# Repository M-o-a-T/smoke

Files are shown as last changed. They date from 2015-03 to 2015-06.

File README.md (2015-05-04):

# Fire Detector

## Gira

The "Gira" board is intended to plug into a "Gira Dual" smoke detector.
This device (30€) has a thermometer as well as a smoke chamber, a
serial interface that's actually useful, and the ability to run on 12V
external as well as 9V battery power.

It runs on 3.3V; the 1wire bus (5V) is connected via a level shifter.

Code will be in https://github.com/M-o-a-T/owslave

## Funk

The "Funk" board is a small (and currently untested) board that connects
a cheap smoke detector to RF. There's no code for it.

## Programming

The programming interface is a standard 6-pin plug, except that it's
used via a 3x2 pogo plug. If you need to attach a 6-pin header, soldering
that to the top of the pads is fairly easy. You should add some
two-component glue after soldering so that you won't pull the pads off when
you unplug.

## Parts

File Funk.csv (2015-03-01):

Bill of Material from rauchmelder.sch, 25 parts, grouped by values, as of 1/30/13 1:05 PM
Part | Value | Device | Package | Description | Description2 | Qty | Place_YES/NO | Povided_by_customer_YES/NO | Distributor | Ordernumber | Weblink | Remarks_customer | Unit_price | Total_price | REMARKS_BETA | OPTION1 | OPTION2 | OPTION3
C1, C2 | 1u | C-EUC0603 | C0603 | CAPACITOR, European symbol |  | 2 | YES | NO | RS | 749-2033
C3, C4 | 100n | C-EUC0603 | C0603 | CAPACITOR, European symbol |  | 2 | YES | NO | RS | 698-3232
D1 | 3V | ZENER-DIODESOD80C | SOD80C | Z-Diode |  | 1 | YES | NO | RS | 710-4339
IC1 | MCP1703CB | MCP1703CB | SOT23 | 250 mA, 16V, Low Quiescent Current LDO Regulator |  | 1 | YES | NO | RS | 669-4907
IC2 | MEGA8-MITQFP | MEGA8-MITQFP | TQFP32-08 | MICROCONTROLLER |  | 1 | YES | NO | RS | 719-4039
IC3 | RFM12B | RFM12B | RFM12B | Radio |  | 1 | YES | NO | RS | 731-2785
Q1, Q4, Q5 | 2N7002_SMD | 2N7002_SMD | SOT23 | N-Channel MOSFET |  | 3 | YES | NO | RS | 708-2396
Q2, Q3 | NX3008 | NX3008 | SOT23 | P-channel MOSFET |  | 2 | YES | NO | RS | 669-7376
R2, R3, R4, R6, R7, R8 | 100k | R-EU_R0603 | R0603 | RESISTOR, European symbol | RESISTOR, 0.1W, 1% | 6 | YES | NO | RS | 697-9438 | http://de.rs-online.com/web/p/products/6979438/?searchTerm=697-9438
R5 | 10k | R-EU_R0603 | R0603 | RESISTOR, European symbol | RESISTOR, 0.1W, 1% | 1 | YES | NO | RS | 697-9325 | http://uk.rs-online.com/web/search/searchBrowseAction.html?method=getProduct&R=6979325

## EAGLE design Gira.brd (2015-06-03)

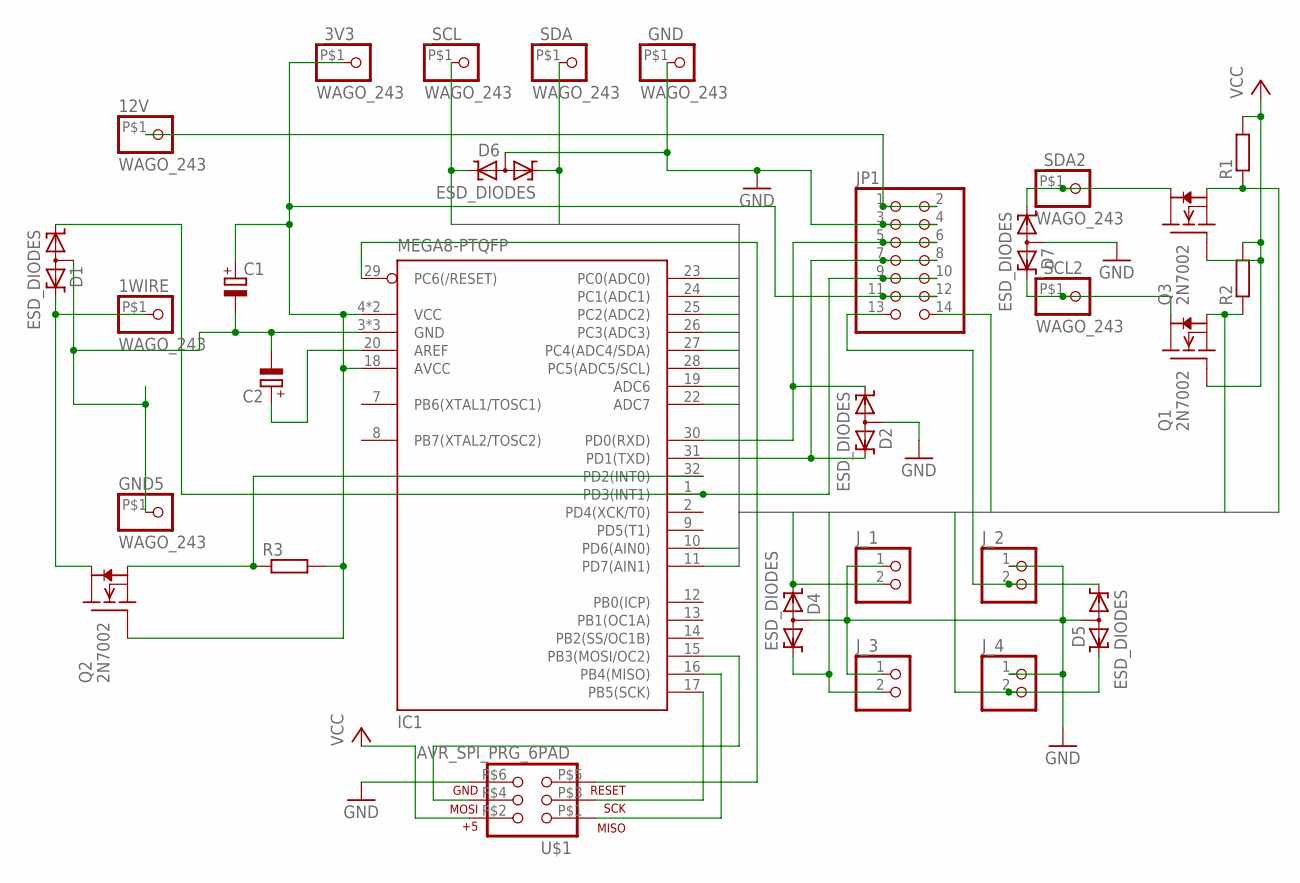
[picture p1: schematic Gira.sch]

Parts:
1WIRE, 12V: WAGO_243
C1, C2: CP1206
D1, D2, D4, D5, D6, D7: ESD_DIODES; SOT23
GND5: WAGO_243
IC1: MEGA8-PTQFP; TQFP32-08
JP1: PINHD-2X7; 2X07
J_1, J_2, J_3, J_4: PINHD-1X2LEVER; 1X02_GN
Q1, Q2, Q3: 2N7002; SOT23
R1, R2, R3: R-EU_R0603; R0603
U$1: AVR_SPI_PRG_6PAD; 2X3_PAD
_3V3: WAGO_243
_GND: WAGO_243
_SCL, _SCL2: WAGO_243
_SDA, _SDA2: WAGO_243

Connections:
3V3: C1.+, IC1.4 (VCC), IC1.6 (VCC), IC1.18 (AVCC), JP1.11, JP1.12, Q2.1 (G), R3.2, U$1.P$2 (2), _3V3.P$1
B1: D4.2 (K2), IC1.23 (PC0(ADC0)), J_1.2
B2: D5.1 (K1), IC1.24 (PC1(ADC1)), J_2.2
B3: D4.1 (K1), IC1.25 (PC2(ADC2)), J_3.2
B4: D5.2 (K2), IC1.26 (PC3(ADC3)), J_4.2
GND: C1.-, C2.-, D1.3 (AA), D2.3 (AA), D4.3 (AA), D5.3 (AA), D6.3 (AA), D7.3 (AA), GND5.P$1, IC1.3 (GND), IC1.5 (GND), IC1.21 (GND), JP1.3, JP1.4, J_1.1, J_2.1, J_3.1, J_4.1, U$1.P$6 (6), _GND.P$1
unnamed: C2.+, IC1.20 (AREF)
unnamed: IC1.32 (PD2(INT0)), Q2.2 (S), R3.1
unnamed: 1WIRE.P$1, D1.2 (K2), Q2.3 (D)
unnamed: D7.1 (K1), Q3.3 (D), _SDA2.P$1
unnamed: D7.2 (K2), Q1.3 (D), _SCL2.P$1
unnamed: IC1.15 (PB3(MOSI/OC2)), U$1.P$4 (4)
unnamed: IC1.16 (PB4(MISO)), U$1.P$1 (1)
unnamed: IC1.17 (PB5(SCK)), U$1.P$3 (3)
unnamed: IC1.29 (PC6(/RESET)), U$1.P$5 (5)
unnamed: 12V.P$1, JP1.1, JP1.2
unnamed: D2.2 (K2), IC1.31 (PD1(TXD)), JP1.7, JP1.8
unnamed: D2.1 (K1), IC1.30 (PD0(RXD)), JP1.5, JP1.6
unnamed: D1.1 (K1), IC1.1 (PD3(INT1)), JP1.9, JP1.10
RESET: IC1.10 (PD6(AIN0)), JP1.13
SCL: D6.2 (K2), IC1.22 (ADC7), _SCL.P$1
SCL2: IC1.28 (PC5(ADC5/SCL)), Q1.2 (S), R2.1
SDA: D6.1 (K1), IC1.19 (ADC6), _SDA.P$1
SDA2: IC1.27 (PC4(ADC4/SDA)), Q3.2 (S), R1.1
TEST: IC1.11 (PD7(AIN1)), JP1.14
VCC: Q1.1 (G), Q3.1 (G), R1.2, R2.2

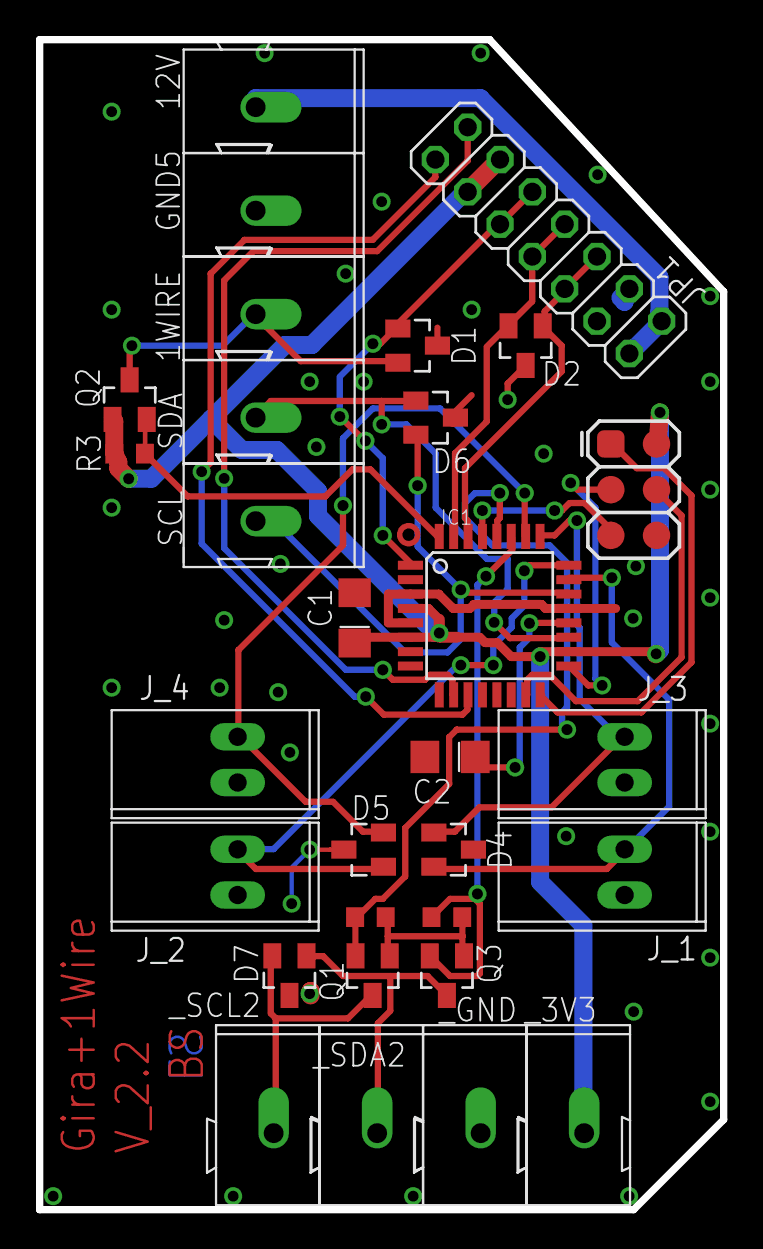
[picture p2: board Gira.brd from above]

Board: 2 copper layers, 38.0 x 65.0 mm, 30 parts (0 on the bottom side), 26 nets.

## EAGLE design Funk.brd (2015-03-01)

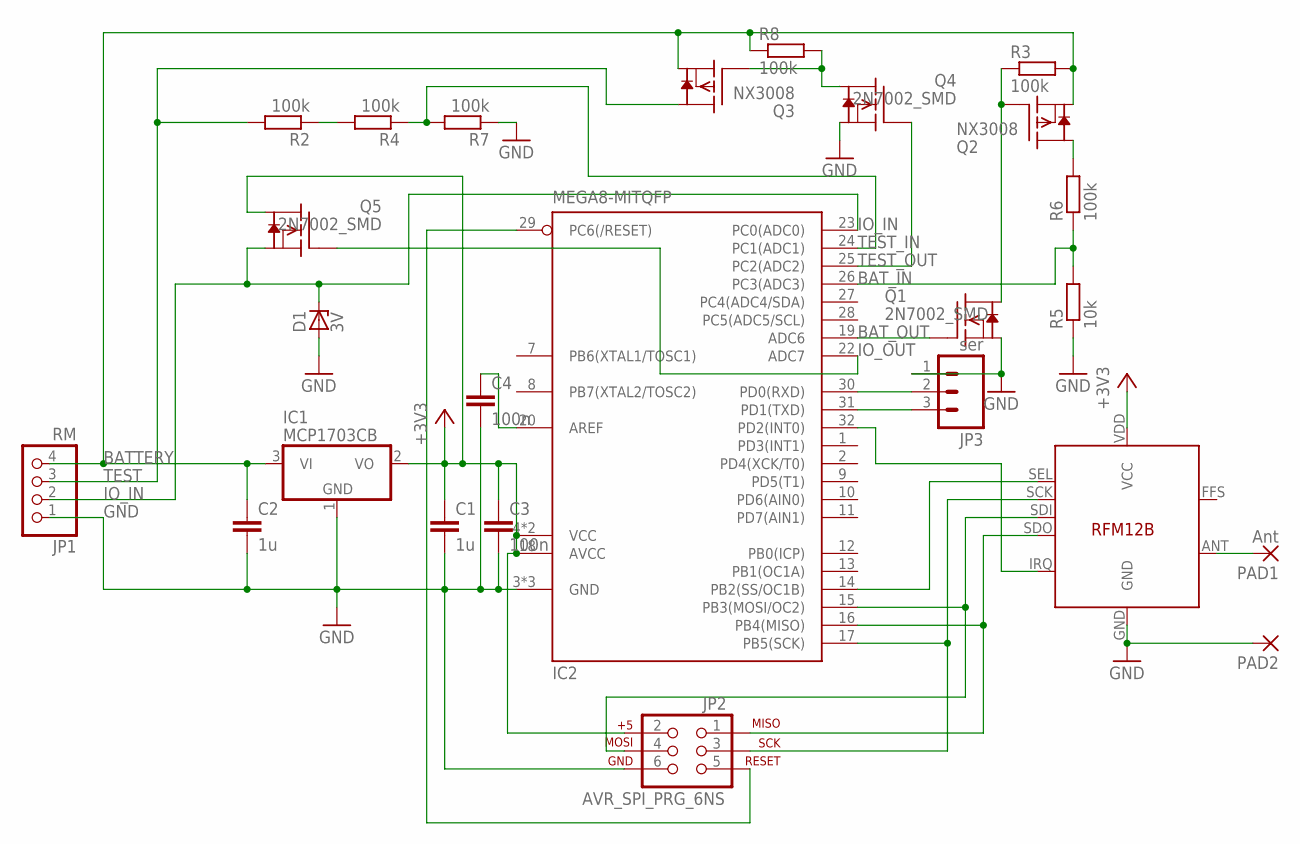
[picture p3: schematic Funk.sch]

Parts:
C1, C2: 1u; C0603
C3, C4: 100n; C0603
D1: 3V; SOD80C
IC1: MCP1703CB; SOT23
IC2: MEGA8-MITQFP; TQFP32-08
IC3: RFM12B; MPN RFM12B-868-S1
JP1: RM; 1X04
JP2: AVR_SPI_PRG_6NS; 2X3-NS
JP3: ser; 1X03
PAD1: Ant; 1,6/0,8
PAD2: 1,6/0,8
Q1, Q4, Q5: 2N7002_SMD; SOT23
Q2, Q3: NX3008; SOT23; MPN NX3008NBK
R2, R3, R4, R6, R7, R8: 100k; R0603
R5: 10k; R0603

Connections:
+3V3: C1.1, C3.1, IC1.2 (VO), IC2.4 (VCC), IC2.6 (VCC), IC2.18 (AVCC), IC3.VDD (VCC), JP2.2, Q5.3 (D)
BATTERY: C2.1, IC1.3 (VI), JP1.4, Q2.2 (S), Q3.2 (S), R3.2, R8.1
BAT_IN: IC2.26 (PC3(ADC3)), R5.2, R6.1
BAT_OUT: IC2.19 (ADC6), Q1.1 (G)
GND: C1.2, C2.2, C3.2, C4.2, D1.A, IC1.1 (GND), IC2.3 (GND), IC2.5 (GND), IC2.21 (GND), IC3.GND, JP1.1, JP2.6, JP3.1, PAD2.1, Q1.2 (S), Q4.2 (S), R5.1, R7.1
IO_IN: D1.C, IC2.23 (PC0(ADC0)), JP1.2, Q5.2 (S)
IO_OUT: IC2.22 (ADC7), Q5.1 (G)
unnamed: R2.1, R4.2
unnamed: IC2.29 (PC6(/RESET)), JP2.5
unnamed: Q2.3 (D), R6.2
unnamed: IC2.16 (PB4(MISO)), IC3.SDO, JP2.1
unnamed: IC2.15 (PB3(MOSI/OC2)), IC3.SDI, JP2.4
unnamed: IC2.17 (PB5(SCK)), IC3.SCK, JP2.3
unnamed: IC2.14 (PB2(SS/OC1B)), IC3.SEL
unnamed: IC2.32 (PD2(INT0)), IC3.IRQ
unnamed: Q1.3 (D), Q2.1 (G), R3.1
unnamed: C4.1, IC2.20 (AREF)
unnamed: IC2.30 (PD0(RXD)), JP3.2
unnamed: IC2.31 (PD1(TXD)), JP3.3
unnamed: IC3.ANT, PAD1.1
unnamed: Q3.1 (G), Q4.3 (D), R8.2
TEST: JP1.3, Q3.3 (D), R2.2
TEST_IN: IC2.24 (PC1(ADC1)), R4.1, R7.2
TEST_OUT: IC2.25 (PC2(ADC2)), Q4.1 (G)

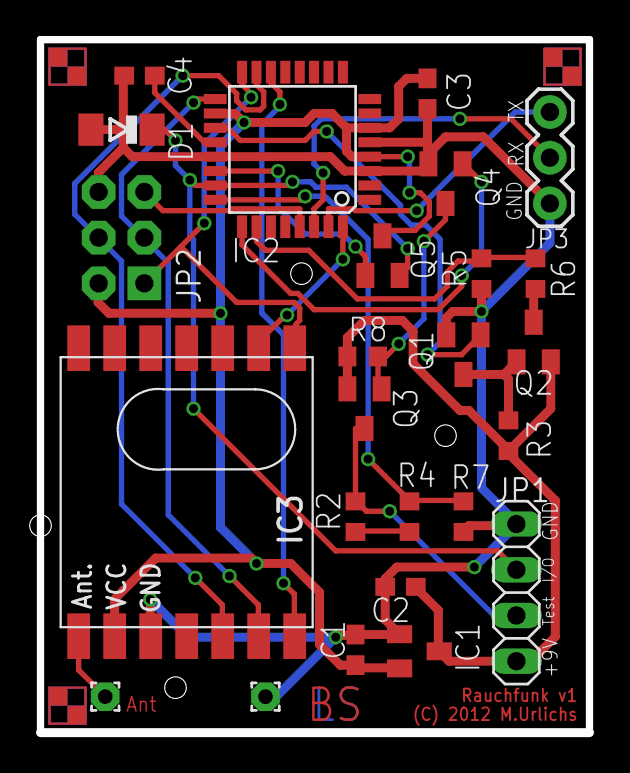
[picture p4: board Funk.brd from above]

Board: 2 copper layers, 30.5 x 38.5 mm, 28 parts (0 on the bottom side), 24 nets.

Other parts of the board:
U$1, U$2, U$3: FIDUCIAL

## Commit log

2015-02-16 "final" versions
    [rauchmelder.brd, rauchmelder.sch]
2015-02-28 Initial check-in of prototype
    [Gira.brd, Gira.sch]
2015-03-01 Additional ground, I²C bus, input for light measurement
    [Gira.brd, Gira.sch]
2015-03-24 Update Gira
    min 0.3mm
    Klemmen gedreht
    [Gira.brd, Gira.sch]
2015-03-24 Gira: längere Pads für CPU
    [Gira.brd, Gira.sch]
2015-05-04 V2.1
    * Umstellung auf 3.3V (aus dem Rauchmelder)
    * keine Pullups am Port
    [Gira.brd, Gira.sch]
2015-05-11 V 2.2
    added Aref capacitor
    fixed power supply via prog connector problem
    [Gira.brd, Gira.sch]

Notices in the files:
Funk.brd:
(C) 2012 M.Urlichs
